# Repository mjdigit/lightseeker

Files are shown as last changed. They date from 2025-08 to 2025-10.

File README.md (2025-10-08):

# LightSeeker
Light Seeker is an unibody wired keyboard which has ortholinear 49 keys and 25mm trackball.
This keyboard was generated by [Auto-Keyboard-Design-Kit](https://auto-kdk.pages.dev/) and QMK firmware has been slightly customized.

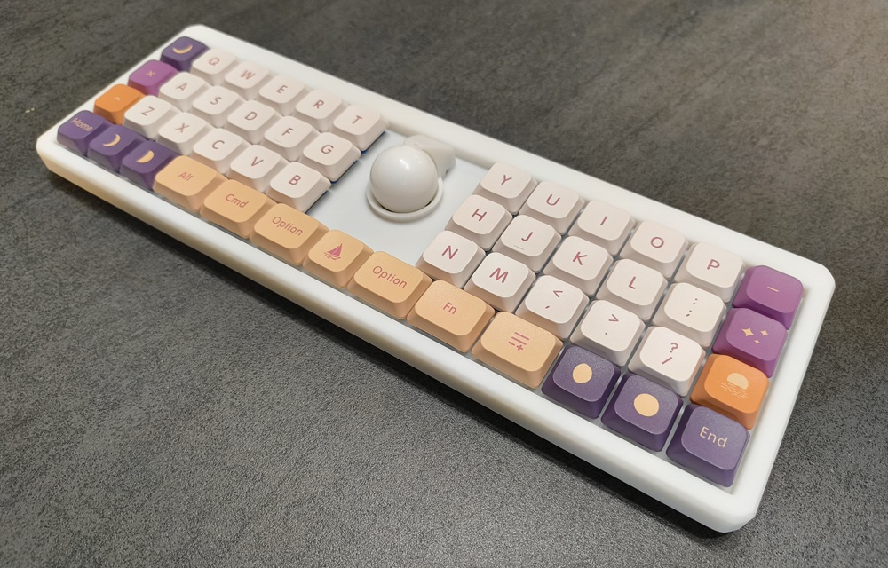
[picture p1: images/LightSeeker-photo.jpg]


## Parts List
### Parts need to be prepared/purchased
|Part|Quantity|Remarks|
|---|---|---|
|Wired controller board (RP2040)|1|Available on BOOTH (https://nogikes.booth.pm/items/6604431)|
|Conthrough(2.5mm, 11pin)|2|Included in the above|
|USB-C cable|1|To connect between PC and the keyboard|
|Choc socket|49|e.g. Kailh PG1350 KeySwitches Contact (CPG135001S30)|
|Choc V2 switch|49||
|Diode|49|e.g. 1N4148W. Not neccesary in the case you assemble it in PCB service.|
|Keycap|49|1u keycap x 43, 1.25u keycap x 6|
|14mm mouse sensor module (PAW3222)|1|Available on BOOTH (https://nogikes.booth.pm/items/6520217)|
|2mm ceramics ball (as support ball)|3||
|FFC cable (150mm length, 0.5mm pitch, 6pin)|1||
|25mm trackball|1||

### Parts need to be ordered/printed
|Part|Quantity|Remarks|
|---|---|---|
|PCB|1|Order a PCB using pcb/LightSeeker-pcb.json|
|Keyboard case (Top)|1|Print a case using case/LightSeeker-top-case.stl|
|Keyboard case (Bottom)|1|Print a case using case/LightSeeker-bottom-case.stl|

## Keyboard build instruction
Please refer the below:

* Keyboard itself: https://github.com/sekigon-gonnoc/auto-kdk
* Trackball: https://github.com/sekigon-gonnoc/auto-kdk/blob/master/manual/TrackBall.md

## Firmware build instruction
### By GitHub Actions
* Fork this repository and let GitHub Actions to build a firmware.

### By QMK Firmware
* <s>[T.B.D.] Firmware may be built by place qmk_firmware/keyboards/lightseeker directory into keyboards directory of QMK firmware then exec `qmk compile -kb lightseeker -lm vial` but I hadn't verified it yet</s> => Useful for build check but firmware is not work.

## Default key layout
### Windows/Linux/Android
Layer0: Default Layer
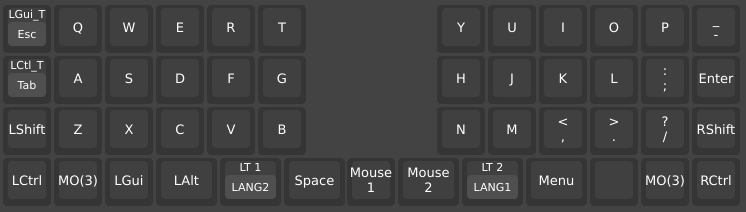
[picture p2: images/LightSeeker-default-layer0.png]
Layer0


Layer1: Function, Number & Punctuation
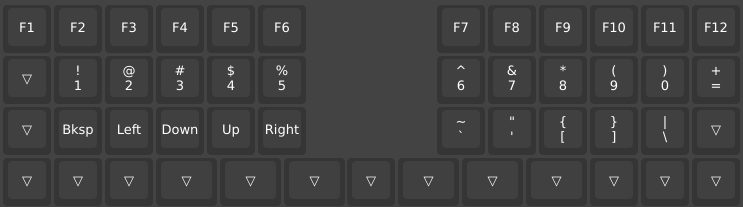
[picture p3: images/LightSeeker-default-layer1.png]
Layer1


Layer2: Command & Cursor Layer
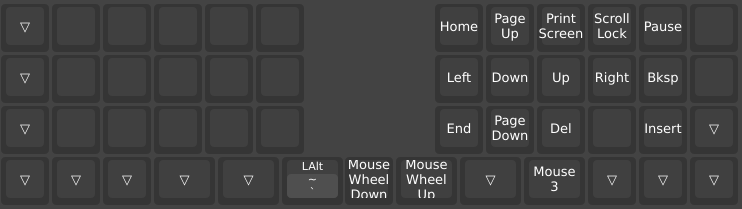
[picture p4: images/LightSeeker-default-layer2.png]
Layer2


Layer3: Numpad
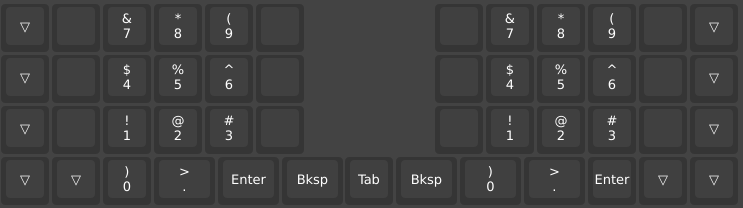
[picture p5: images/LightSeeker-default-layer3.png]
Layer3


### MacOS/iOS
自動判定を有効にする場合は、rules.mkにてOS_DETECTION_ENABLEをyesに設定してください。

Layer4: Default Layer
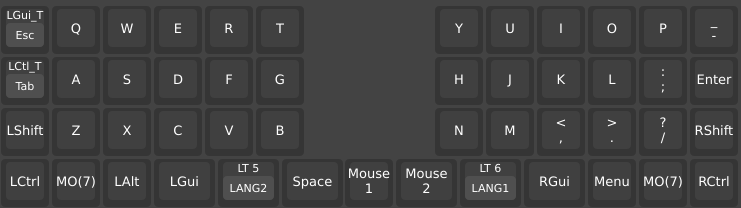
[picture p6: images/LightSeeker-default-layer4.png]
Layer4


Layer5: Function, Number & Punctuation
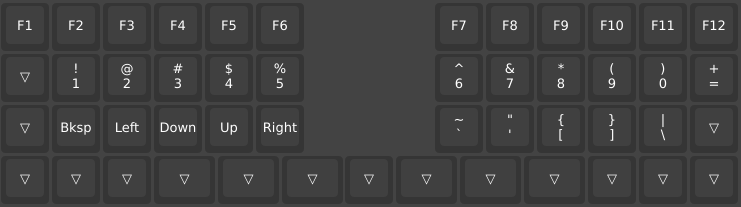
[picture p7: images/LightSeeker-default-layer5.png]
Layer5


Layer6: Command & Cursor Layer
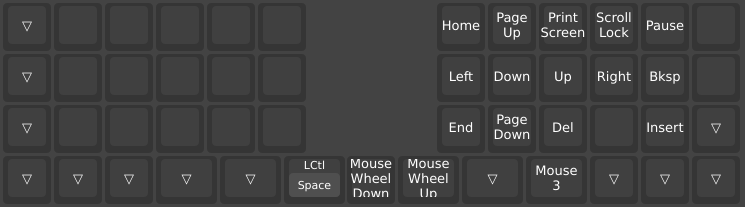
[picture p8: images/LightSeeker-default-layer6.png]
Layer6


Layer7: Numpad
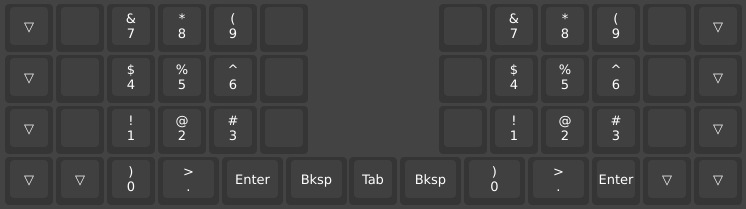
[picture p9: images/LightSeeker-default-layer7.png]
Layer7


## Note) Customizations on QMK firmware from originally generated by Auto-KDK
* Fixed the bug that the firmware didn't recognize one column in right side of the keyboard.
* Increased number of layers to 8.
* Enabled OS detection and place default layer of MacOS/iOS into layer#4.
* Added drag-scroll (scroll using trackball) functionality.

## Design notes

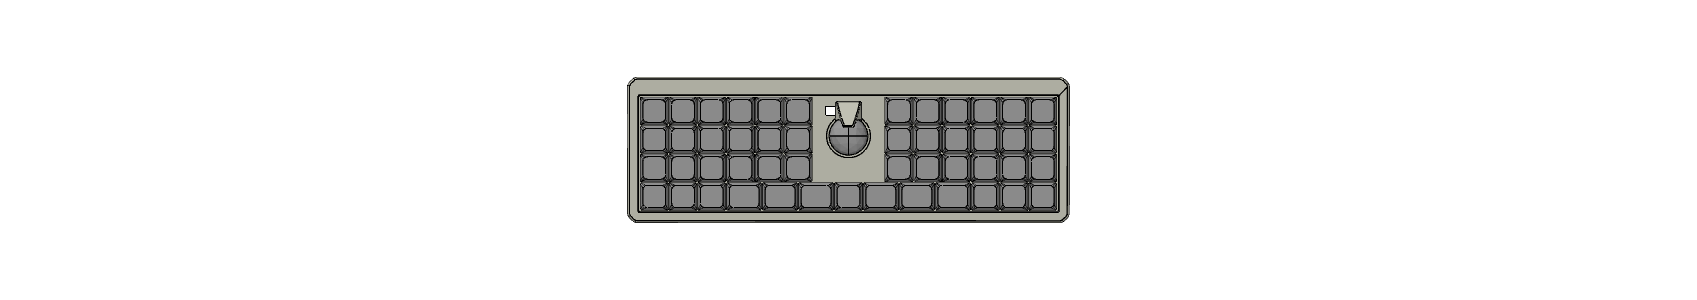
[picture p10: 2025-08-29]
images/LightSeeker-top-view.png

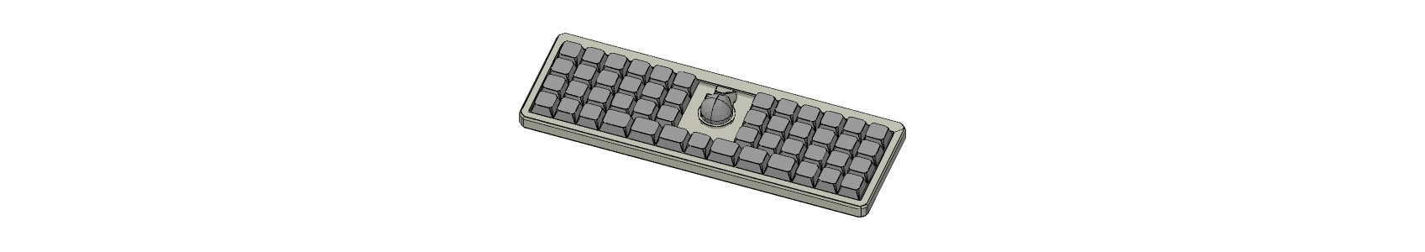
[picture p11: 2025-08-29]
images/LightSeeker-case-preview.png

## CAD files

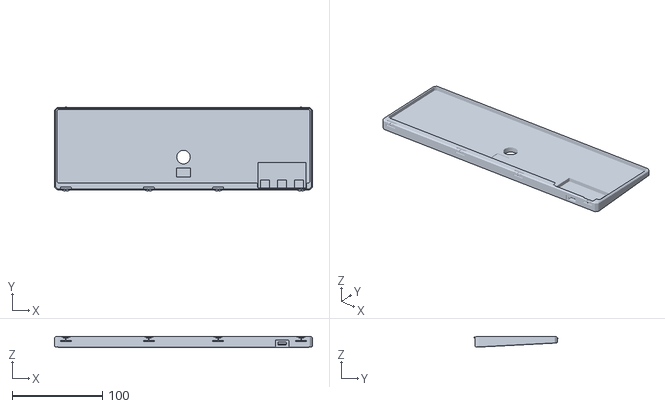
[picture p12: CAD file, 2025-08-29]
case/LightSeeker-bottom-case.stl
285.9 x 93.6 x 11.6

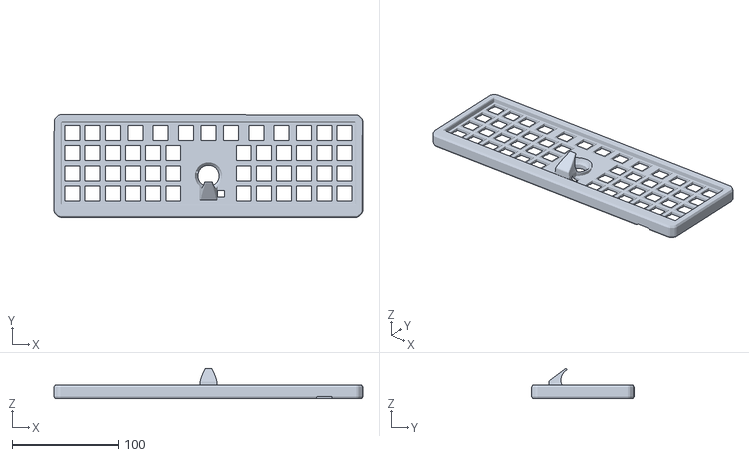
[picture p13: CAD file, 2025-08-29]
case/LightSeeker-top-case.stl
291.5 x 96.9 x 28.7

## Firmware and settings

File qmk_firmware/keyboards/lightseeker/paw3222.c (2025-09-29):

/* Copyright 2021 Gompa (@Gompa)
 * Modifications Copyright 2025 sekigon-gonnoc
 *
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
 * You should have received a copy of the GNU General Public License
 * along with this program.  If not, see <http://www.gnu.org/licenses/>.
 */

// https://github.com/shinoaliceKabocha/choco60_track/tree/master/keymaps/default

#include "quantum.h"

#include "pointing_device.h"

#include "debug.h"
#include "gpio.h"
#include "paw3222.h"
#include "pointing_device_internal.h"
#include "wait.h"

#define REG_PID1 0x00
#define REG_PID2 0x01
#define REG_STAT 0x02
#define REG_X 0x03
#define REG_Y 0x04
#define REG_CONFIGURATION 0x06
#define REG_CPI_X 0x0D
#define REG_CPI_Y 0x0E

#define REG_PROTECT 0x09

#define VAL_PROTECT_DISABLE 0x5A
#define VAL_PROTECT_ENABLE 0x00

#define constrain(amt, low, high)                                              \
  ((amt) < (low) ? (low) : ((amt) > (high) ? (high) : (amt)))

#define DRGSCRL_MODE_OFF  0b00
#define DRGSCRL_MODE_VRT  0b01
#define DRGSCRL_MODE_HOR  0b10
#define DRGSCRL_MODE_FRE  0b11
typedef union {
    uint32_t raw;
    struct {
        uint8_t  dragscroll_mode: 2; // 00b: off, 01b: vertical, 10b: horizontal, 11b: free
    } __attribute__((packed));
} paw3222_config_t;
static paw3222_config_t g_paw3222_config = {0};

/**
    Get the current state of drag scroll mode.
    @return 00b: off, 01b: vertical, 10b: horizontal, 11b: free
**/
static uint8_t get_pointer_dragscroll_mode(void) {
    return g_paw3222_config.dragscroll_mode;
}

/**
    Set drag scroll mode.
    @param [in] mode    00b: off, 01b: vertical, 10b: horizontal, 11b: free.
**/
static void set_pointer_dragscroll_mode(uint8_t mode) {
    g_paw3222_config.dragscroll_mode = mode & 0b11;
}

// CPI values
enum cpi_values {
  CPI400,  // 0b000
  CPI500,  // 0b001
  CPI600,  // 0b010
  CPI800,  // 0b011
  CPI1000, // 0b100
  CPI1200, // 0b101
  CPI1600, // 0b110
};

#define CPI_STEP 38
#define CPI_MIN (16 * CPI_STEP)
#define CPI_MAX (127 * CPI_STEP)

uint8_t paw3222_serial_read(void);
void paw3222_serial_write(uint8_t reg_addr);
uint8_t paw3222_read_reg(uint8_t reg_addr);
void paw3222_write_reg(uint8_t reg_addr, uint8_t data);

const pointing_device_driver_t paw3222_pointing_device_driver = {
    .init = paw3222_init,
    .get_report = paw3222_get_report,
    .set_cpi = paw3222_set_cpi,
    .get_cpi = paw3222_get_cpi,
};

void paw3222_init(void) {
  gpio_write_pin_high(PAW3222_CS_PIN);       // set cs pin high
  gpio_set_pin_output(PAW3222_CS_PIN);       // set cs pin to output
  gpio_write_pin_high(PAW3222_SCLK_PIN);     // set clock pin high
  gpio_set_pin_output(PAW3222_SCLK_PIN);     // setclockpin to output
  gpio_set_pin_input_high(PAW3222_SDIO_PIN); // set datapin input high

  paw3222_write_reg(REG_CONFIGURATION, 0x80); // reset sensor
  wait_ms(2);

  paw3222_read_reg(0x00); // read id
  paw3222_read_reg(0x01); // read id2
  paw3222_read_reg(0x02);
  paw3222_read_reg(0x03);
  paw3222_read_reg(0x04);
  paw3222_read_reg(0x12);
}

uint8_t paw3222_serial_read(void) {
  gpio_set_pin_input(PAW3222_SDIO_PIN);
  uint8_t byte = 0;

  for (uint8_t i = 0; i < 8; ++i) {
    gpio_write_pin_low(PAW3222_SCLK_PIN);
    wait_us(1);

    byte = (byte << 1) | gpio_read_pin(PAW3222_SDIO_PIN);

    gpio_write_pin_high(PAW3222_SCLK_PIN);
    wait_us(1);
  }

  return byte;
}

void paw3222_serial_write(uint8_t data) {
  gpio_write_pin_low(PAW3222_SDIO_PIN);
  gpio_set_pin_output(PAW3222_SDIO_PIN);

  for (int8_t b = 7; b >= 0; b--) {
    gpio_write_pin_low(PAW3222_SCLK_PIN);
    if (data & (1 << b)) {
      gpio_write_pin_high(PAW3222_SDIO_PIN);
    } else {
      gpio_write_pin_low(PAW3222_SDIO_PIN);
    }
    gpio_write_pin_high(PAW3222_SCLK_PIN);
  }

  wait_us(4);
}

report_paw3222_t paw3222_read(void) {
  report_paw3222_t data = {0};

  data.isMotion = paw3222_read_reg(REG_STAT) &
                  (1 << 7); // check for motion only (bit 7 in field)
  data.x = (int8_t)paw3222_read_reg(REG_X);
  data.y = (int8_t)paw3222_read_reg(REG_Y);

  return data;
}

void paw3222_write_reg(uint8_t reg_addr, uint8_t data) {
  gpio_write_pin_low(PAW3222_CS_PIN); // set cs pin low
  paw3222_serial_write(0b10000000 | reg_addr);
  paw3222_serial_write(data);
  gpio_write_pin_high(PAW3222_CS_PIN); // set cs pin high
}

uint8_t paw3222_read_reg(uint8_t reg_addr) {
  gpio_write_pin_low(PAW3222_CS_PIN); // set cs pin low
  paw3222_serial_write(reg_addr);
  wait_us(5);
  uint8_t reg = paw3222_serial_read();
  gpio_write_pin_high(PAW3222_CS_PIN); // set cs pin high

  return reg;
}

void paw3222_set_cpi(uint16_t cpi) {
  if (cpi < CPI_MIN) {
    cpi = CPI_MIN;
  } else if (cpi > CPI_MAX) {
    cpi = CPI_MAX;
  }
  uint8_t cpival = (cpi + (CPI_STEP >> 1)) / CPI_STEP;

  paw3222_write_reg(REG_PROTECT, VAL_PROTECT_DISABLE);
  paw3222_write_reg(REG_CPI_X, cpival);
  paw3222_write_reg(REG_CPI_Y, cpival);
  paw3222_write_reg(REG_PROTECT, VAL_PROTECT_ENABLE);
}

uint16_t paw3222_get_cpi(void) {
  return paw3222_read_reg(REG_CPI_X) * CPI_STEP;
}

uint8_t read_pid_paw3222(void) { return paw3222_read_reg(REG_PID1); }

report_mouse_t paw3222_get_report(report_mouse_t mouse_report) {
  report_paw3222_t data = paw3222_read();
  uint8_t dragscroll_mode;
  static int16_t scroll_buffer_x = 0;
  static int16_t scroll_buffer_y = 0;
  int16_t datax = 0;
  int16_t datay = 0;

  if (data.isMotion) {
    dragscroll_mode = get_pointer_dragscroll_mode();
    if (dragscroll_mode) {
      // Drag scroll movement
      datax = data.x;
      datay = data.y;

      // Support rotation of the sensor data
#     if defined(POINTING_DEVICE_ROTATION_90)
      datax = data.y;
      datay = -data.x;
#     elif defined(POINTING_DEVICE_ROTATION_180)
      datax = -data.x;
      datay = -data.y;
#     elif defined(POINTING_DEVICE_ROTATION_270)
      datax = -data.y;
      datay = data.x;
#     else
      datax = data.x;
      datay = data.y;
#     endif

      // Support Inverting the X and Y Axises
#     if defined(POINTING_DEVICE_INVERT_X)
      datax = -datax;
#     endif
#     if defined POINTING_DEVICE_INVERT_Y
      datay = -datay;
#     endif

      pd_dprintf("Drag ] H: %d, V: %d\n", datax, datay);
#     if PAW3222_IS_FREE_SCROLL_SNAPPED
      // Allow either of horizontal or vertical movement
      if ((dragscroll_mode & DRGSCRL_MODE_FRE) == DRGSCRL_MODE_FRE) {
        dragscroll_mode = (datax*datax > datay*datay)? DRGSCRL_MODE_HOR: DRGSCRL_MODE_VRT;
      }
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

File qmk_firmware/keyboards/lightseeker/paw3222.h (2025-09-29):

/* Copyright 2021 Gompa (@Gompa)
 * Modifications Copyright 2025 sekigon-gonnoc
 *
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
 * You should have received a copy of the GNU General Public License
 * along with this program.  If not, see <http://www.gnu.org/licenses/>.
 */

#pragma once

#include "pointing_device.h"
#include <stdbool.h>
#include <stdint.h>

#ifndef PAW3222_SCLK_PIN
#ifdef POINTING_DEVICE_SCLK_PIN
#define PAW3222_SCLK_PIN POINTING_DEVICE_SCLK_PIN
#else
#define PAW3222_SCLK_PIN 18
#endif
#endif
#ifndef PAW3222_SDIO_PIN
#ifdef POINTING_DEVICE_SDIO_PIN
#define PAW3222_SDIO_PIN POINTING_DEVICE_SDIO_PIN
#else
#define PAW3222_SDIO_PIN 19
#endif
#endif
#ifndef PAW3222_CS_PIN
#ifdef POINTING_DEVICE_CS_PIN
#define PAW3222_CS_PIN POINTING_DEVICE_CS_PIN
#else
#define PAW3222_CS_PIN 21
#endif
#endif

enum paw3222_keycodes {
    DRGSCRL_V = QK_KB_0, // Set vertical drag scroll mode
    DRGSCRL_H,           // Set horizontal drag scroll mode
    DRGSCRL_F,           // Set free drag scroll mode
};
#define PAW3222_IS_FREE_SCROLL_SNAPPED   1
#define PAW3222_DRGSCRL_BUFFER_THRESHOLD 6

typedef struct {
  int16_t x;
  int16_t y;
  bool isMotion;
} report_paw3222_t;

const pointing_device_driver_t paw3222_pointing_device_driver;

/**
 * @brief Initializes the sensor so it is in a working state and ready to
 * be polled for data.
 *
 * @return true Initialization was a success
 * @return false Initialization failed, do not proceed operation
 */
void paw3222_init(void);

/**
 * @brief Reads and clears the current delta, and motion register values on the
 * given sensor.
 *
 * @return pmw33xx_report_t Current values of the sensor, if errors occurred all
 * fields are set to zero
 */

report_paw3222_t paw3222_read(void);
/**
 * @brief Sets the given CPI value the sensor. CPI is  often refereed to
 * as the sensors sensitivity. Values outside of the allowed range are
 * constrained into legal values.
 *
 * @param cpi CPI value to set
 */
void paw3222_set_cpi(uint16_t cpi);

/**
 * @brief Gets the currently set CPI value from the sensor. CPI is often
 * refereed to as the sensors sensitivity.
 *
 * @return uint16_t Current CPI value of the sensor
 */
uint16_t paw3222_get_cpi(void);

report_mouse_t paw3222_get_report(report_mouse_t mouse_report);

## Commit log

2025-08-29 Copy Auto-KDK files.
    [oball49-bottom-case.stl, oball49-top-case.stl]
2025-08-29 Changed keyboard name
    [LightSeeker-bottom-case.stl, LightSeeker-top-case.stl, oball49-bottom-case.stl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]
2025-09-18 Fixed very basically mis-implimentation on switch-case.
    [paw3222.c]
2025-09-19 Added rotation & invert logic in drag scroll functionality.
    [paw3222.c, paw3222.h]
2025-09-21 Bugfix: Drag Scroll Reduction Ratio logic doesn't work when the value is minus.
    [paw3222.c]
2025-09-29 Fix: Made Drag-scroll smoother
    [paw3222.c, paw3222.h]

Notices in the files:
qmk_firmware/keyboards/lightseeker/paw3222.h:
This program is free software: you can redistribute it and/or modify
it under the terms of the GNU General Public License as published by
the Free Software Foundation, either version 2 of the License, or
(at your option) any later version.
